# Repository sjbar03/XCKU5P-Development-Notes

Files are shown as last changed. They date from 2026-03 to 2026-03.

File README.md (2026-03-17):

# XCKU5P Development Notes

A repository of all my notes as I learn PCB Design, Xilinx UltraScale+ FPGA, and Vivado.

Huge thanks to the creator of [this repository](https://github.com/tommythorn/AliExpressXCKU5P) for compiling all of the relevant technical info on this board!

Table of Contents
>    [1. VGA](./vga.md)
> 
>    [2. HDMI](./hdmi.md)
> 
>    [3. Protocols](./protocols.md)
> 
>    [4. PCB](./pcb.md)

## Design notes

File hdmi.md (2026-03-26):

# HDMI

19 pin connector, 8 of which are 4 TMDS pairs (1). 

## TMDS 
Encodes 8 bits to 10 bits. First bit is untransformed. Two stages.
1. Next 7 bits is XOR or XNOR transformed against the bit before it. Chooses XOR/XNOR to minimize transitions. Ninth bit represents whether XOR or XNOR was used. 
2. First 8 bits optionally inverted to even out 0s and 1s - sustained DC level. Tenth bit indicates if this happended. (2)

A pair of TMDS signals are complementary: two wires of the pair have opposite signals.

## Transmitter Chip (ADV7513)
Because this FPGA does not have the GTY pins routed, we have to use the HP pins to drive an external transmitter chip. I've chosen to go with the ubiquitous [ADV7513](/Datasheets/C408901%20-%20HDMI.pdf) from Analog Devices. It's very cheap, relatively simple, widely supported, and can handle the HDMI spec I'm going for (1.4). 

We will use HP IO at 1.8V (LVCMOS18) to drive the digital inputs of this chip. We also need to connect a 3.3V power supply, and a 1.8V power supply. 

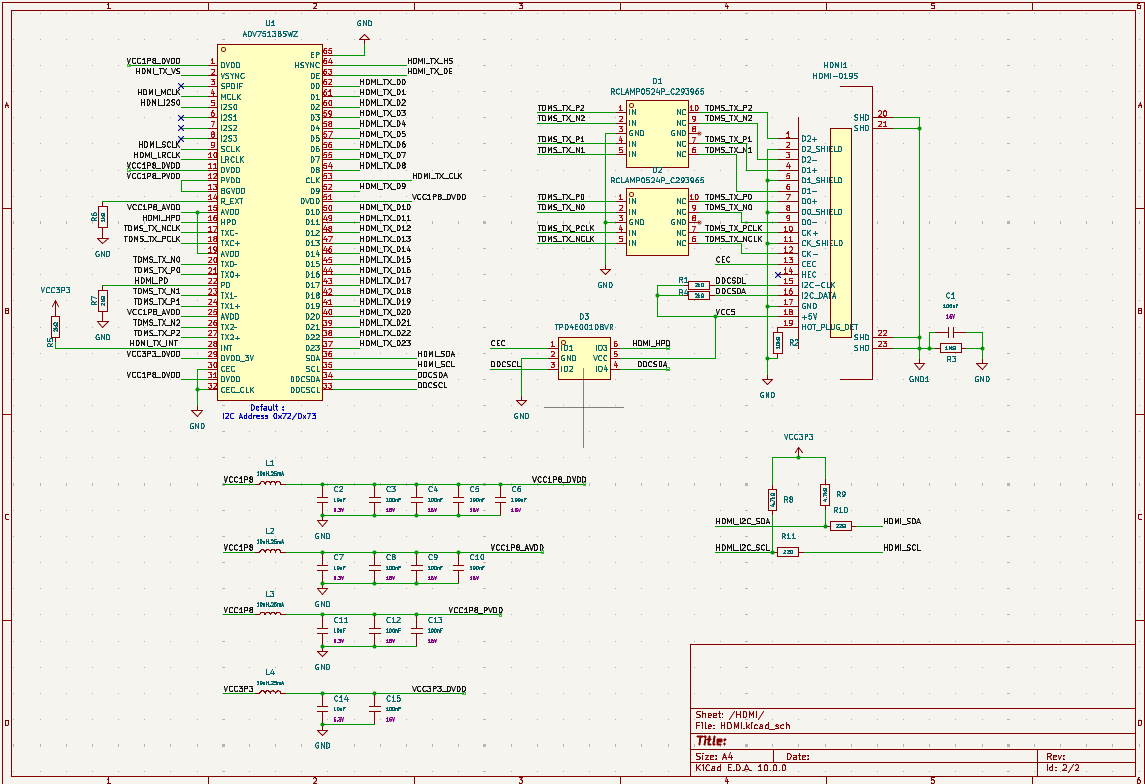
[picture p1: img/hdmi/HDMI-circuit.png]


Above is the circuit I will be using to drive the ADV7513. This circuit is nearly identical to the HDMI circuit used on the [Altera DE10 FPGA](/Datasheets/de10-nano-schematic-711128.pdf).

<!-- ### On FPGA
The XCKU5P does not have HR I/O that support TMDS. The HDMI IP from Xilinx supports GTYE4 for UltraScale+ devices: the GTY pins on this board. I will use the <a href="/Documentation/pg230-vid-phy-controller-en-us-2.2.pdf">Video PHY Controller</a> and <a href="/Documentation/pg235-v-hdmi-tx-ss-en-us-3.2 (1).pdf">HDMI 1.4 TX</a> Xilinx IP. The outputs of the Video PHY Controller can then be exported to the specific GTY pins chosen for the HDMI port.

The HDMI subsystem will be implemented following the HDMI example for the KC705 Evaluation Board. A screenshot of the block diagram can be found <a href="/Documentation/hdmi-subsys-example.pdf">here</a> but directions for loading this example are in PG235 (3p.87).

Pins to be used (tentative)
* AE8   MGTYTXN1_224                 
* AD6   MGTYTXN2_224                 
* AF6   MGTYTXN0_224                 
* AC4   MGTYTXN3_224                 
* AF7   MGTYTXP0_224                 
* AE9   MGTYTXP1_224                 
* AD7   MGTYTXP2_224                 
* AC5   MGTYTXP3_224                 

All of these pins are GTY pins on bank 224. They make up 4 sets of TX differential pairs.

Currently trying to figure out if my core board even exposes the GTY pins. (Not looking good)

## Roadblock
The AliExpress XCKU5P board does not expose any of the GTY pins on the FPGA - so the Xilinx HDMI Transmitter IP cannot be (easily) used for my purposes. Because of this I am switching to implementing VGA using the high-density (at 3.3V) I/O. These notes will remain for future reference.  -->

# Sources
(1) https://www.fpga4fun.com/HDMI.html <cr>
(2) https://en.wikipedia.org/wiki/Transition-minimized_differential_signaling <cr>
(3) https://www.amd.com/content/dam/xilinx/support/documents/ip_documentation/v_hdmi_tx_ss/v3_0/pg235-v-hdmi-tx-ss.pdf <cr>

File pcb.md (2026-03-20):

# PCB Design!

This breakout board is my first PCB design, so I want to take some notes on the progress I'm making.

## VGA Circuit 
I started with the VGA circuit because I have experience with VGA circuits with the RP2040 MCU and it seemed simple. Additionally, video out is an obvious need for FPGA - graphical acceleration is one of the coolest FPGA niches. (Opinion)

### Rev. 1
<div style="text-align:center">
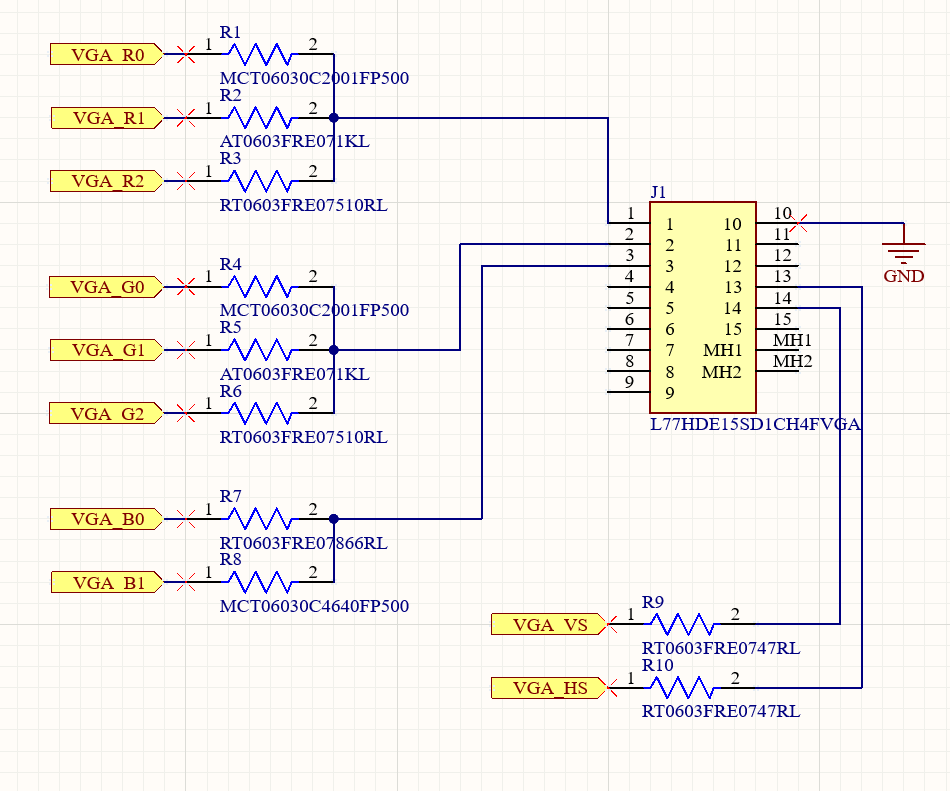
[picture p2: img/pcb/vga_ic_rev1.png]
    
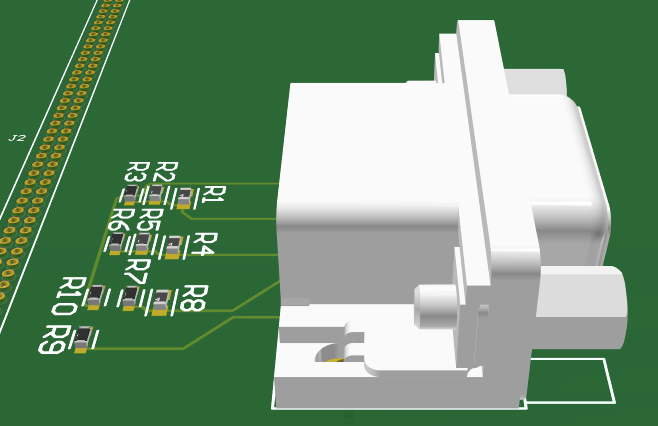
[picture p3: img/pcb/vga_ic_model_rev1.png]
    
</div>

Revision 1! I have the schematic designed and used the Altium auto-router to see what it would look like on the PCB. It's definitely not the final form of this circuit, but it's my first and I think it looks alright.

### Rev. 2
For this revision, I've switched from through hole headers for the receptacles to a surface mount header that allows me to route underneath the header. This is convenient for routing the inner-IO to the edge of the board. Because of this, I was able to re-route the VGA wiring again, and add a 40 pin 0.1" GPIO bank for easy breadboarding. 

I've also added a large GND pour on the 4th layer to connect all GND togethers simply.

<div style="text-align:center">
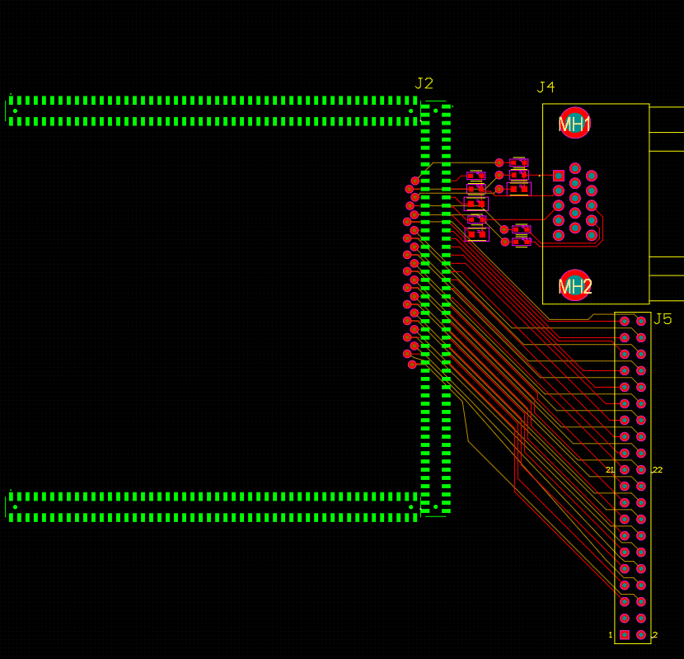
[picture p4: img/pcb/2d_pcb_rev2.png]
    
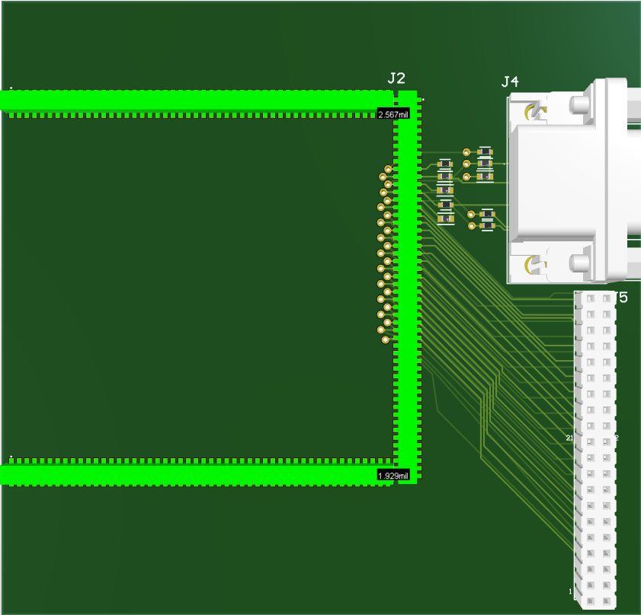
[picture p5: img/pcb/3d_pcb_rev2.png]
    
</div>

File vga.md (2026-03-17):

# VGA 

The VGA protocol is refreshingly simple, and will only use 10 GPIO on the FPGA.

* 3 bits red channel - 3b Ladder DAC
* 3 bits green channel - 3b Ladder DAC
* 2 bits blue channel - 2b Ladder DAC
* 1 bit HSYNC - digital
* 1 bit VSYNC - digital

<div style="text-align:center">
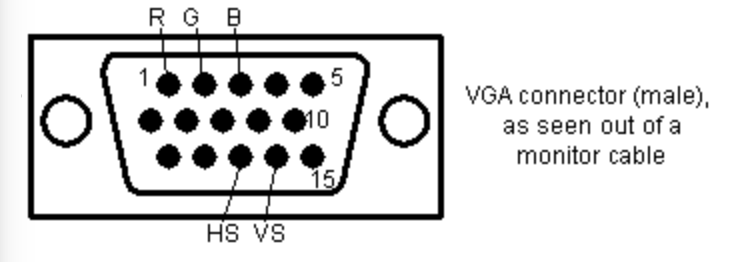
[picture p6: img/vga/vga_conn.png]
    
</div>

Here is a diagram of the VGA Connector with the 5 pins we care about indicated. Taken from (1). 

## Frequency of HD I/O
The high-density I/O on the XCKU5P can operate at 3.3V with a maximum data rate of 250Mb/s DDR (double data rate). For our use case, we will configure these pins to be SDR with a maximum effective rate of 125MHz (plenty fast for the VGA pixel rate).

## Binary Weighted DAC
For simplicity we are going with a Binary Weighted Resistor DAC. This design uses one resistor per bit, so we'll need 8 total (3 for Red, 3 for Green, 2 for Blue). I've drafted the circuit in LTspice and included an image below. In this circuit, I inclued the 75Ohm terminating resistor that is found inside most VGA monitors. I have also included a waveform of the spice simulation showing the output voltage at each step.

<div style="text-align:center">
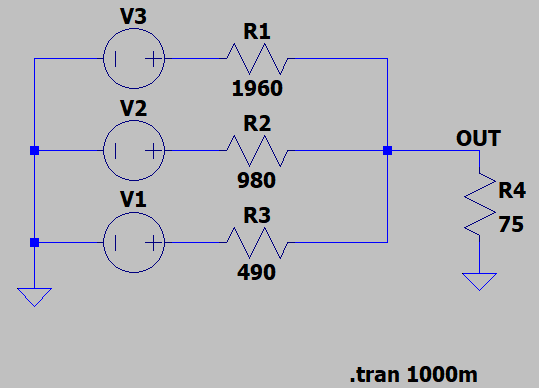
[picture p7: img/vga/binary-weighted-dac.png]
    
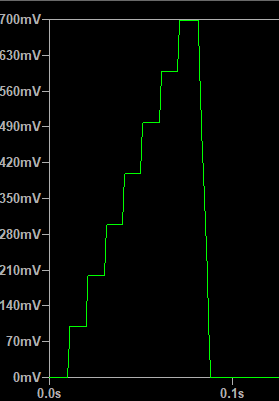
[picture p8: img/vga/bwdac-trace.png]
    
</div>

### BWD Math
The math for the binary weighted DAC is simple. We want our output signal to be 0V to 0.7V, and our input volatge is 3.3V. For a simple voltage divider, we would need a resistance of 325 Ohms to achieve an output of 0.7V.

$$ V_{out} = V_{in} * \frac{R_2}{R_1 + R_2} $$

$$ R_1 = (R_2 * \frac{V_{in}}{V_{out}}) - R2 $$

$$ R_1 = (75\Omega * \frac{3.3V}{0.7V}) - 75\Omega \approx 280 \Omega $$

We just calculated the Thevenin Resistance of the DAC looking from the output. We want to turn this into a set of three resistances weighted appropriately to represent the magnitude of each bit. Lower order bits should get higher resistance (larger division) and vice-versa.

$$ \frac{1}{R_0} + \frac{1}{2R_0} + \frac{1}{4R_0} = \frac{1}{R_1} $$
$$ R_0 = 490 $$
$$ R_{B0} = 1960, R_{B1} = 980, R_{B2} = 490 $$

These are the theoretical resistor values for each bit in a three bit DAC. In reality, we will choose the closest available resistor - above the desired value (to prevent over-voltage). We also calculate for a two bit DAC.

$$ \frac{1}{R_0} + \frac{1}{2R_0} = \frac{1}{R_1} $$
$$ R_0 = 420 $$
$$ R_{B0} = 840, R_{B1} = 420 $$

Now we have our full Digital to Analog VGA circuit - ready to be drafted and put on a PCB.

## FPGA Implementation

For this use case, we're going to need 8 pins for color, 1 pin for HSync, and 1 pin for VSync. 10 pins total! This is super light for video output, which is why I chose VGA for my first breakout board design.

Since we're using the HD pins on the AliExpress board we'll choose 10 adjacent pins from our pinout: 

    * AD15 - RED[2]
    * AF15 - GREEN[2]
    * AF14 - RED[1]
    * AF13 - GREEN[1]
    * AE15 - RED[0]
    * AE13 - GREEN[0]
    * AD14 - HS
    * AD13 - BLUE[0]
    * AC14 - VS
    * AC13 - BLUE[1]

These pins are all in the J2 bank on the AliExpress board, specifically bank 84. I chose adjacent pins in the same bank for consistency, and I assigned pins to each signal in an attempt to prioritize shorter runs for more important signals.

Here are two images of the current design.

<div style="text-align:center">
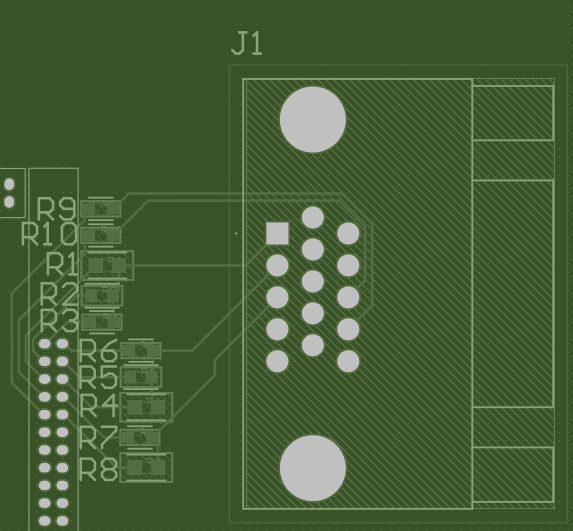
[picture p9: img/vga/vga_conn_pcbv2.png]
    
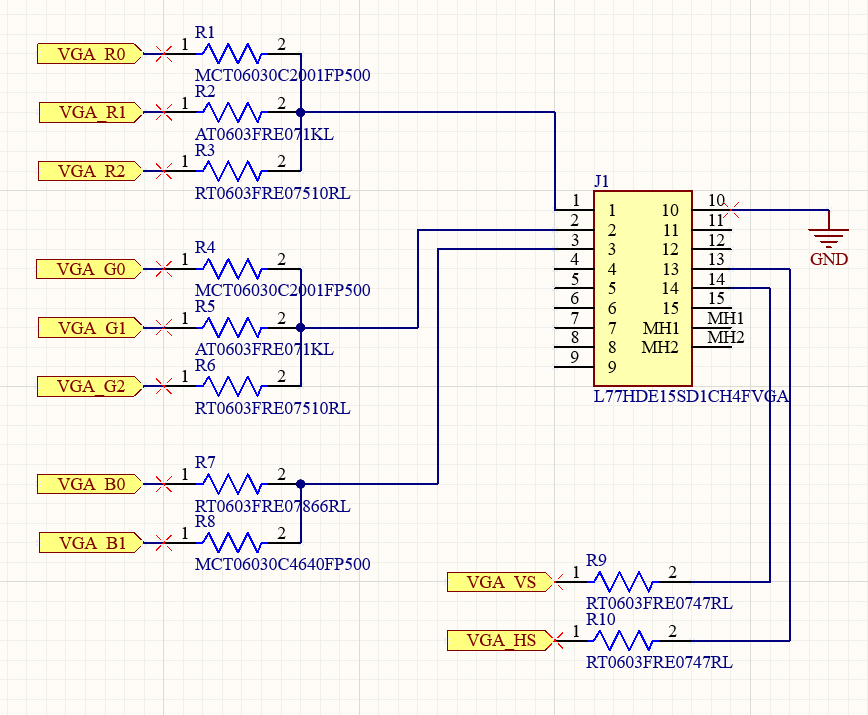
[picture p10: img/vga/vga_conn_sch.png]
    
</div>

I will have to implement the VGA driver from scratch since there is no Xilinx IP, although I will have plenty of inspiration to go off of. Two great reference for a Verilog VGA driver is FPGA4FUN (1) and Hunter Adam's + Bruce Land's ECE5760 (4).

# Sources
(1) https://www.fpga4fun.com/VGA.html <cr>

(2) https://austinmorlan.com/posts/fpga_computer_vga/

(3) https://www.electronics-tutorials.ws/combination/digital-to-analogue-converter.html

(4) https://people.ece.cornell.edu/land/courses/ece5760/DE1_SOC/HPS_peripherials/Examples_version_18.html

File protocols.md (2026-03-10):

## LVDS
These TMDS pairs would typically be implemented on HR pins (older Xilinx). The XCKU5P only has HD and HP IO banks - we'll use high-performance and go with a 1.8V LVDS (Low Voltage Differential Signaling) (1p.121)

Only available on the HP I/O Banks
* $V_{CCO}$ = 1.8v
* DIFF_TERM_ADV = TERM_100
* DIFF_TERM = TRUE

<div style="text-align:center">
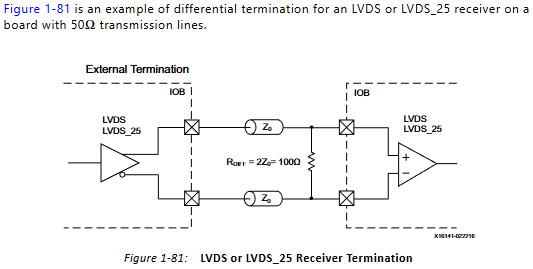
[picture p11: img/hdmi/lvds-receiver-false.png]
    
</div>

An example of the receiver circuitry if DIFF_TERM = FALSE.

<div style="text-align:center">
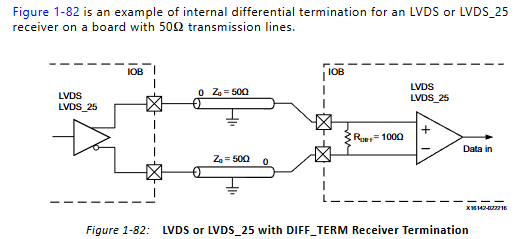
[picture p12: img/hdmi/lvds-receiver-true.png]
    
</div>

And an example of the receiver circuitry if DIFF_TERM = TRUE. This is what I will be going with in this project. Note the formula:

$$R_{DIFF} = 2Z_0$$

This indicates that DIFF_TERM_ADV should be adjusted according to the resistance in the transmission lines.

# Sources
(1) https://docs.amd.com/v/u/en-US/ug571-ultrascale-selectio

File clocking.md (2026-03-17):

# Clocking and MMCM
This AliExpress XCKU5P comes with one 100MHz crystal oscillator onboard. This oscillator is terminated to FPGA pins T25 and U25 as an LVDS differential pair (P and N, respectively).

Deriving a single-ended clock signal from this pair can be done like so: 

    IBUFDS clk_buf (
        .I(clk_p),
        .IB(clk_n),
        .O(clk)
    );

## MMCM Multiplication
If 100MHz is too slow (as it hopefully will be!), we can multiply this clock using the Mixed Mode Clock Manager primitives provided in Vivado. Docs on the MMCM are <a href=https://docs.amd.com/r/en-US/ug572-ultrascale-clocking/MMCM-Ports>here</a>

In general, MMCM can be used like this: (taken from Google AI Result, will be refined later)

    MMCME4_BASE #(
    .BANDWIDTH("OPTIMIZED"),   // Jitter programming
    .CLKFBOUT_MULT_F(12.0),    // Multiply value (2.000-64.000)
    .CLKFBOUT_PHASE(0.0),      // Phase offset of feedback
    .CLKIN1_PERIOD(10.0),      // Input period in ns (100 MHz)
    .CLKOUT0_DIVIDE_F(6.0),    // Divide value for CLKOUT0 (resulting in 200MHz)
    .CLKOUT0_DUTY_CYCLE(0.5),
    .CLKOUT0_PHASE(0.0),
    .DIVCLK_DIVIDE(1)          // Master division value (1-106)
    )
    MMCME4_BASE_inst (
    .CLKOUT0(clk_200mhz),      // 200 MHz output clock
    .CLKFBOUT(clk_fb),         // Feedback clock output
    .CLKFBIN(clk_fb),          // Feedback clock input
    .CLKIN1(clk_100mhz),       // 100 MHz input clock
    .PWRDWN(1'b0),             // Power down signal
    .RST(reset),               // Reset signal
    .LOCKED(locked)            // Output indicating clock is stable
    );

We want our VCO to operate in its safe range, which is 800MHz to 1600MHz on the Kintex UltraScale+ FPGAs. Multiplying by 12 will allow our VCO to run at 1200MHz, then divided by 6 to achieve 200MHz output on clk200mhz.

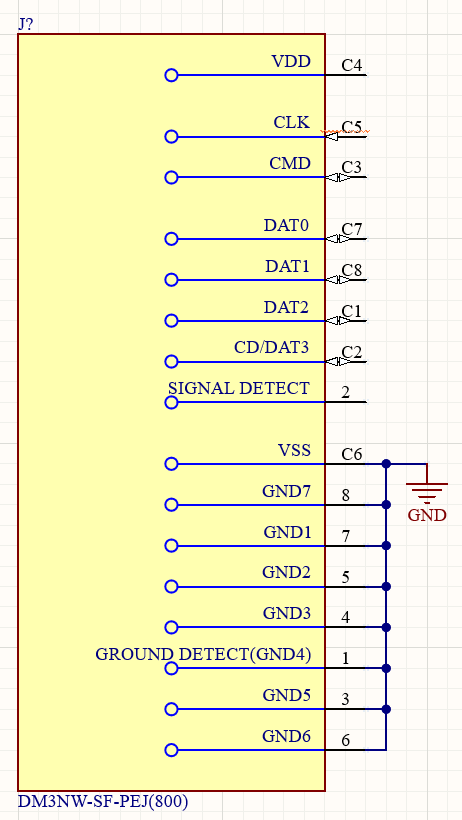
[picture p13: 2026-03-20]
img/sdcard/pinout.png

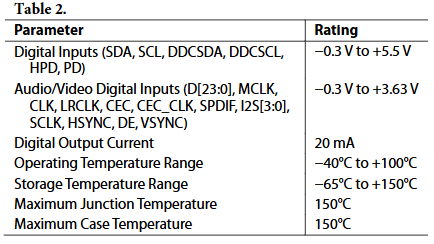
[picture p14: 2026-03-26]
img/hdmi/ADV-inputs.png

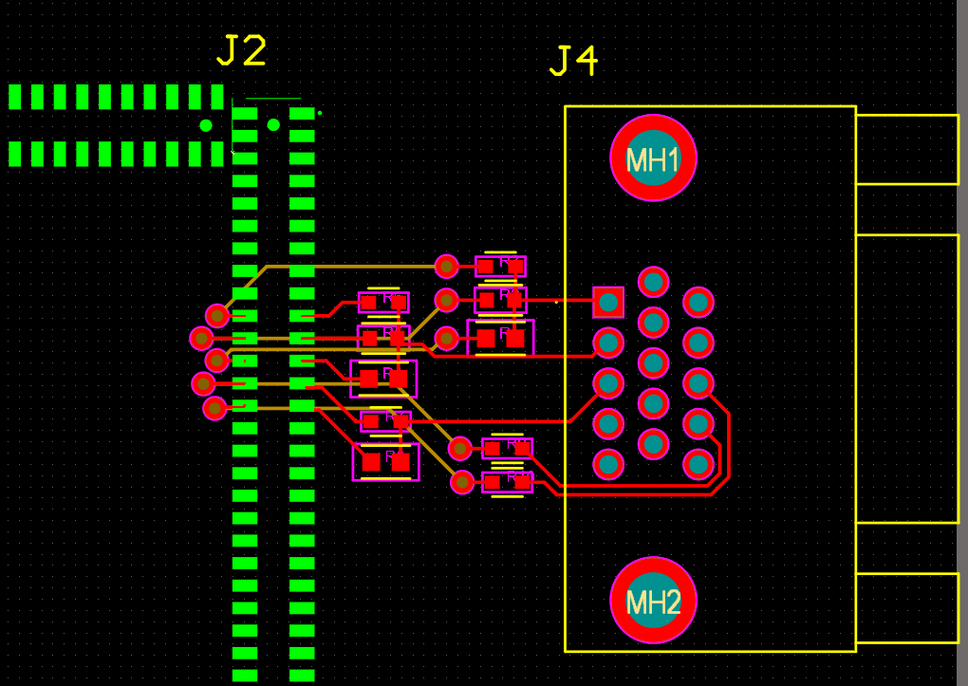
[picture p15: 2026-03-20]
img/pcb/vga_ic_rev2.png

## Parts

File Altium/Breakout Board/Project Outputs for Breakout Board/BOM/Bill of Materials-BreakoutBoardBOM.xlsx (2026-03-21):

Line # | Name | Description | Designator | Revision ID | Revision State | Revision Status | Quantity | LCSC Part Number | Manufacturer 1 | Manufacturer Part Number 1 | Manufacturer Lifecycle 1 | Supplier 1 | Supplier Part Number 1 | Supplier Unit Price 1 | Supplier Subtotal 1 | Footprint
 | DM3AT-SF-PEJM5 | Connector | J6 |  | Not managed |  | 1 | C114218 | HIROSE ELECTRIC | DM3AT-SF-PEJM5 | Volume Production | Mouser | 798-DM3AT-SF-PEJM5 | 2.66 | 2.66 | DM3ATSFPEJM5
 | LTST-C190KRKT | LED | LED0, LED1, LED2, LED3, LED4, LED5, LED6, LED7 |  | Not managed |  | 8 | C94869 | Lite-On | LTST-C190KRKT | Volume Production | Conrad | 1127460 | 0.05786 | 0.46286 | LEDC1608X80N
 | 0402WGF2001TCE | Resistor, 2kΩ, ±1%, 62.5mW, 50V, ±100ppm/℃, -55℃~+155℃, SMD 0402 | R1, R4 |  | Not managed |  | 2 | C4109 |  |  |  | LCSC | C4109 |  |  | RES-0402
 | 0402WGF1001TCE | Resistor, 1kΩ, ±1%, 62.5mW, 50V, ±100ppm/℃, -55℃~+155℃, SMD 0402 | R2, R5 |  | Not managed |  | 2 | C11702 |  |  |  | LCSC | C11702 |  |  | RES-0402
 | 0402WGF5100TCE | Resistor, 510Ω, ±1%, 62.5mW, 50V, ±100ppm/℃, -55℃~+155℃, SMD 0402 | R3, R6, R8 |  | Not managed |  | 3 | C25123 |  |  |  | LCSC | C25123 |  |  | RES-0402
 | 0603WAF8200T5E | Resistor, 820Ω, ±1%, 100mW, 75V, ±100ppm/℃, -55℃~+155℃, SMD 0603 | R7 |  | Not managed |  | 1 | C23253 |  |  |  | LCSC | C23253 |  |  | RES-0603
 | 0603WAF470JT5E | Resistor, 47Ω, ±1%, 100mW, 75V, ±100ppm/℃, -55℃~+155℃, SMD 0603 | R9, R10 |  | Not managed |  | 2 | C23182 |  |  |  | LCSC | C23182 |  |  | RES-0603
 | 0603WAF1002T5E | Resistor, 10kΩ, ±1%, 100mW, 75V, ±100ppm/℃, -55℃~+155℃, SMD 0603 | R11, R12, R13, R14, R15, R16, R17, R18, R19, R20, R21, R22, R23, R24 |  | Not managed |  | 14 | C25804 |  |  |  | LCSC | C25804 |  |  | RES-0603
 | 0402WGF2000TCE | Resistor, 200Ω, ±1%, 62.5mW, 50V, ±100ppm/℃, -55℃~+155℃, SMD 0402 | R25, R26, R27, R28, R29, R30, R31, R32 |  | Not managed |  | 8 | C25087 |  |  |  | LCSC | C25087 |  |  | RES-0402
 | JS202011JCQN | SWITCH SLIDE DPDT 300MA 6V | SW0, SW1, SW2, SW3, SW4, SW5, SW6, SW7, SW8, SW9 | CMP-10038-000009-1 | New From Design | Up to date | 10 | C221665 | C&K Components | JS202011JCQN | Volume Production | DigiKey | CKN10723CT-ND | 0.738 | 7.38 | FP-JS202011JCQN-MFG
 | TS-1185-B-A-B-A | Tactile switch ROHS, SPST Surface Mount, -30C +85C 1.6N 12V 2mm 3mm 4mm 50mA Black no round button | SW10, SW11, SW12, SW13 |  | Not managed |  | 4 | C561517 |  |  |  |  |  |  |  | TS-1185-B-A-B-A

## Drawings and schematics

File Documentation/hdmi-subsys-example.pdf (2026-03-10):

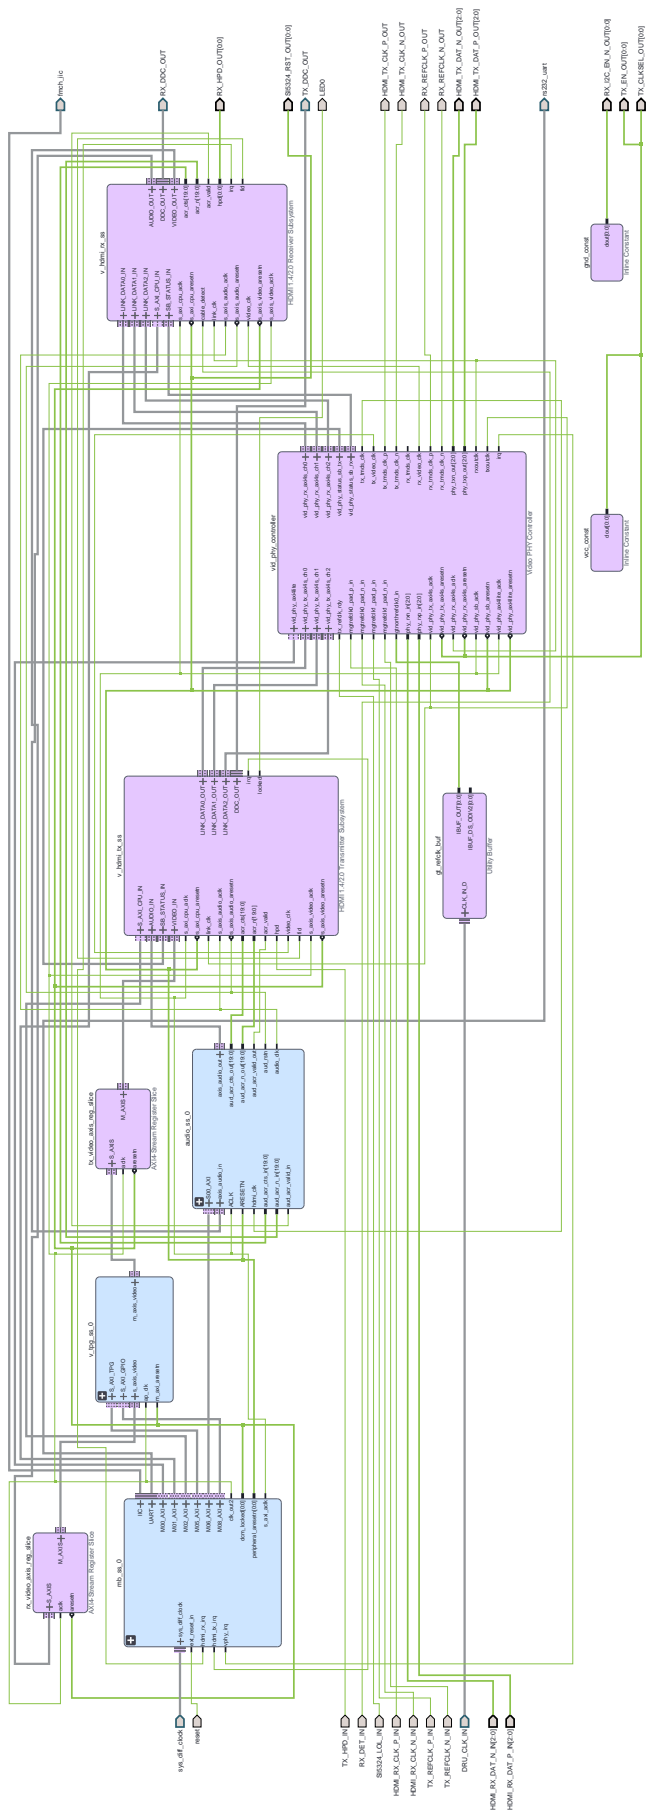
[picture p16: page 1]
DRU_CLK_IN; HDMI_RX_DAT_N_IN[2:0]; HDMI_RX_DAT_P_IN[2:0]; RX_DDC_OUT; RX_HPD_OUT[0:0]; SI5324_RST_OUT[0:0]; TX_DDC_OUT; HDMI_TX_DAT_N_OUT[2:0]; HDMI_TX_DAT_P_OUT[2:0]; RX_I2C_EN_N_OUT[0:0]; TX_EN_OUT[0:0]; TX_CLKSEL_OUT[0:0]; audio_ss_0; S00_AXI; axis_audio_in axis_audio_out ACLK; ARESETN; hdmi_clk; aud_acr_cts_in[19:0]; aud_acr_n_in[19:0]; aud_acr_valid_in; aud_acr_cts_out[19:0]; aud_acr_n_out[19:0]; aud_acr_valid_out; aud_rstn; audio_clk; fmch_iic; gnd_const; Inline Constant; dout[0:0]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

HDMI 1.4/2.0 Receiver Subsystem

Video PHY Controller

HDMI 1.4/2.0 Transmitter Subsystem

AXI4-Stream Register Slice

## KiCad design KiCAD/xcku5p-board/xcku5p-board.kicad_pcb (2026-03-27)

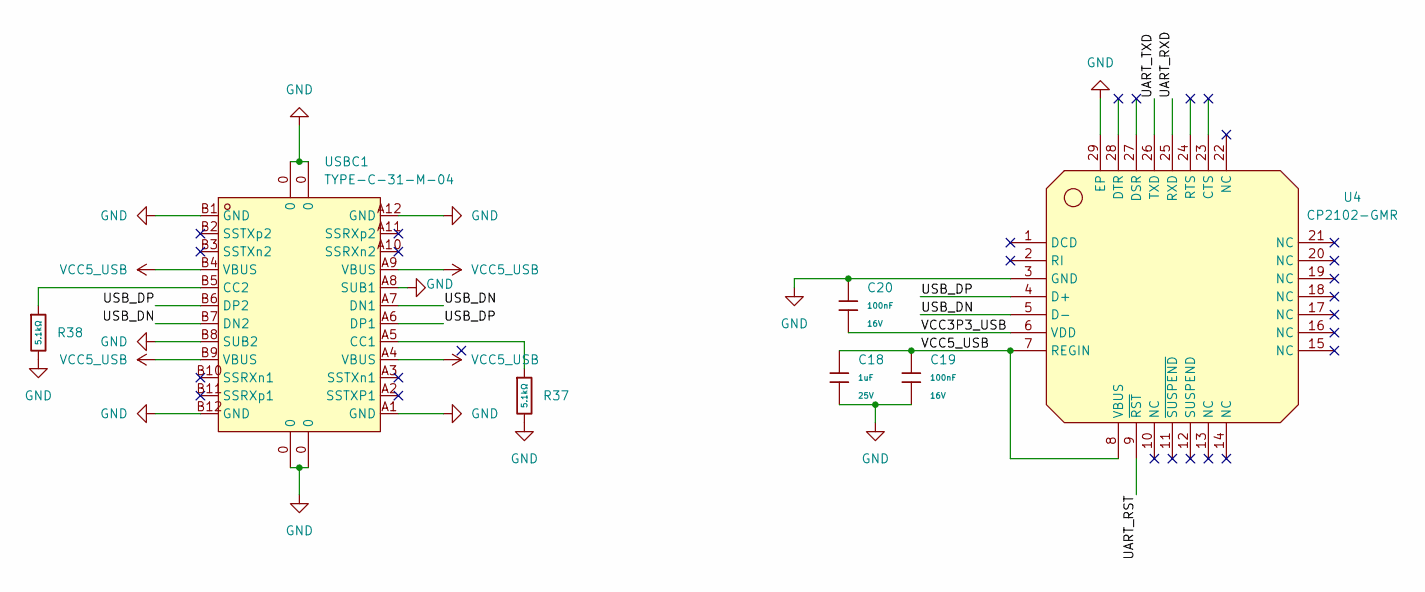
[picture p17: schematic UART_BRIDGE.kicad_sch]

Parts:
C18: 1uF; C_0402; Voltage Rated 25V; Tolerance ±10%; Part CL05A105KA5NQNC; LCSC C52923
C19, C20: 100nF; C_0402; Voltage Rated 16V; Tolerance ±10%; Part CL05B104KO5NNNC; LCSC C1525
R37, R38: 5.1kΩ; R_0402; Overload Voltage (Max) 50V; Tolerance ±1%; Part 0402WGF5101TCE; LCSC C25905
U4: CP2102-GMR; WQFN-28_L5.0-W5.0-P0.50-BL-EP3.2; LCSC Part C6568
USBC1: TYPE-C-31-M-04; USB-C-SMD_TYPE-C-USB-20; LCSC Part C129018

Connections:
/UART_BRIDGE/UART_RST: U4.9 (~RST)
/UART_BRIDGE/UART_RXD: U4.25 (RXD)
/UART_BRIDGE/UART_TXD: U4.26 (TXD)
/UART_BRIDGE/USB_DN: U4.5 (D-), USBC1.A7 (DN1), USBC1.B7 (DN2)
/UART_BRIDGE/USB_DP: U4.4 (D+), USBC1.A6 (DP1), USBC1.B6 (DP2)
/UART_BRIDGE/VCC3P3_USB: C20.2, U4.6 (VDD)
GND: C18.2, C19.2, C20.1, R37.2, R38.2, U4.3 (GND), U4.29 (EP), USBC1.0, USBC1.A1 (GND), USBC1.A8 (SUB1), USBC1.A12 (GND), USBC1.B1 (GND), USBC1.B8 (SUB2), USBC1.B12 (GND); also elsewhere on the board
unnamed: R37.1, USBC1.A5 (CC1)
unnamed: R38.1, USBC1.B5 (CC2)
VCC5_USB: C18.1, C19.1, U4.7 (REGIN), U4.8 (VBUS), USBC1.A4 (VBUS), USBC1.A9 (VBUS), USBC1.B4 (VBUS), USBC1.B9 (VBUS)

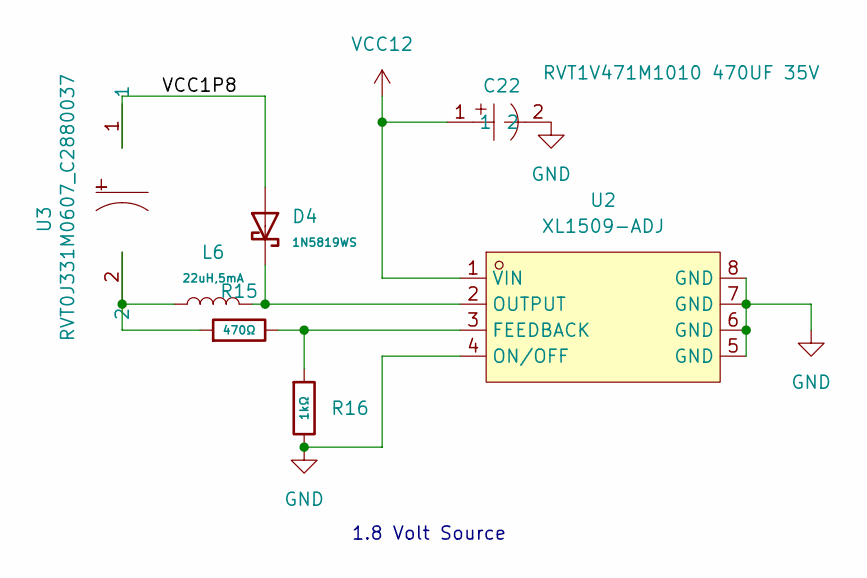
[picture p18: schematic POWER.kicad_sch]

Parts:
C22: RVT1V471M1010 470UF 35V; CAP-SMD_BD10.0-L10.3-W10.3-FD; LCSC Part C976030
D4: 1N5819WS; D_SOD-323; Forward Voltage (Vf@If) 600mV@1A; Reverse Voltage (Vr) 40V; Part 1N5819WS; LCSC C191023
L6: 22uH,5mA; L_0805; Tolerance ±10%; Part SDFL2012T220KTF; LCSC C32375
R15: 470Ω; R_0402; Overload Voltage (Max) 50V; Tolerance ±1%; Part 0402WGF4700TCE; LCSC C25117
R16: 1kΩ; R_0402; Overload Voltage (Max) 50V; Tolerance ±1%; Part 0402WGF1001TCE; LCSC C11702
U2: XL1509-ADJ; SOIC-8_L5.0-W4.0-P1.27-LS6.0-BL; LCSC Part C2681227
U3: RVT0J331M0607_C2880037; CAP-SMD_BD6.3-L6.6-W6.6-LS7.2-R-RD-1; LCSC Part C2880037

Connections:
/POWER/VCC1P8: D4.2, U3.1
GND: C22.2, R16.2, U2.4 (ON/OFF), U2.5 (GND), U2.6 (GND), U2.7 (GND), U2.8 (GND); also elsewhere on the board
unnamed: L6.1, R15.1, U3.2
unnamed: R15.2, R16.1, U2.3 (FEEDBACK)
unnamed: D4.1, L6.2, U2.2 (OUTPUT)
VCC12: C22.1, U2.1 (VIN)

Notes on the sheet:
1.8 Volt Source

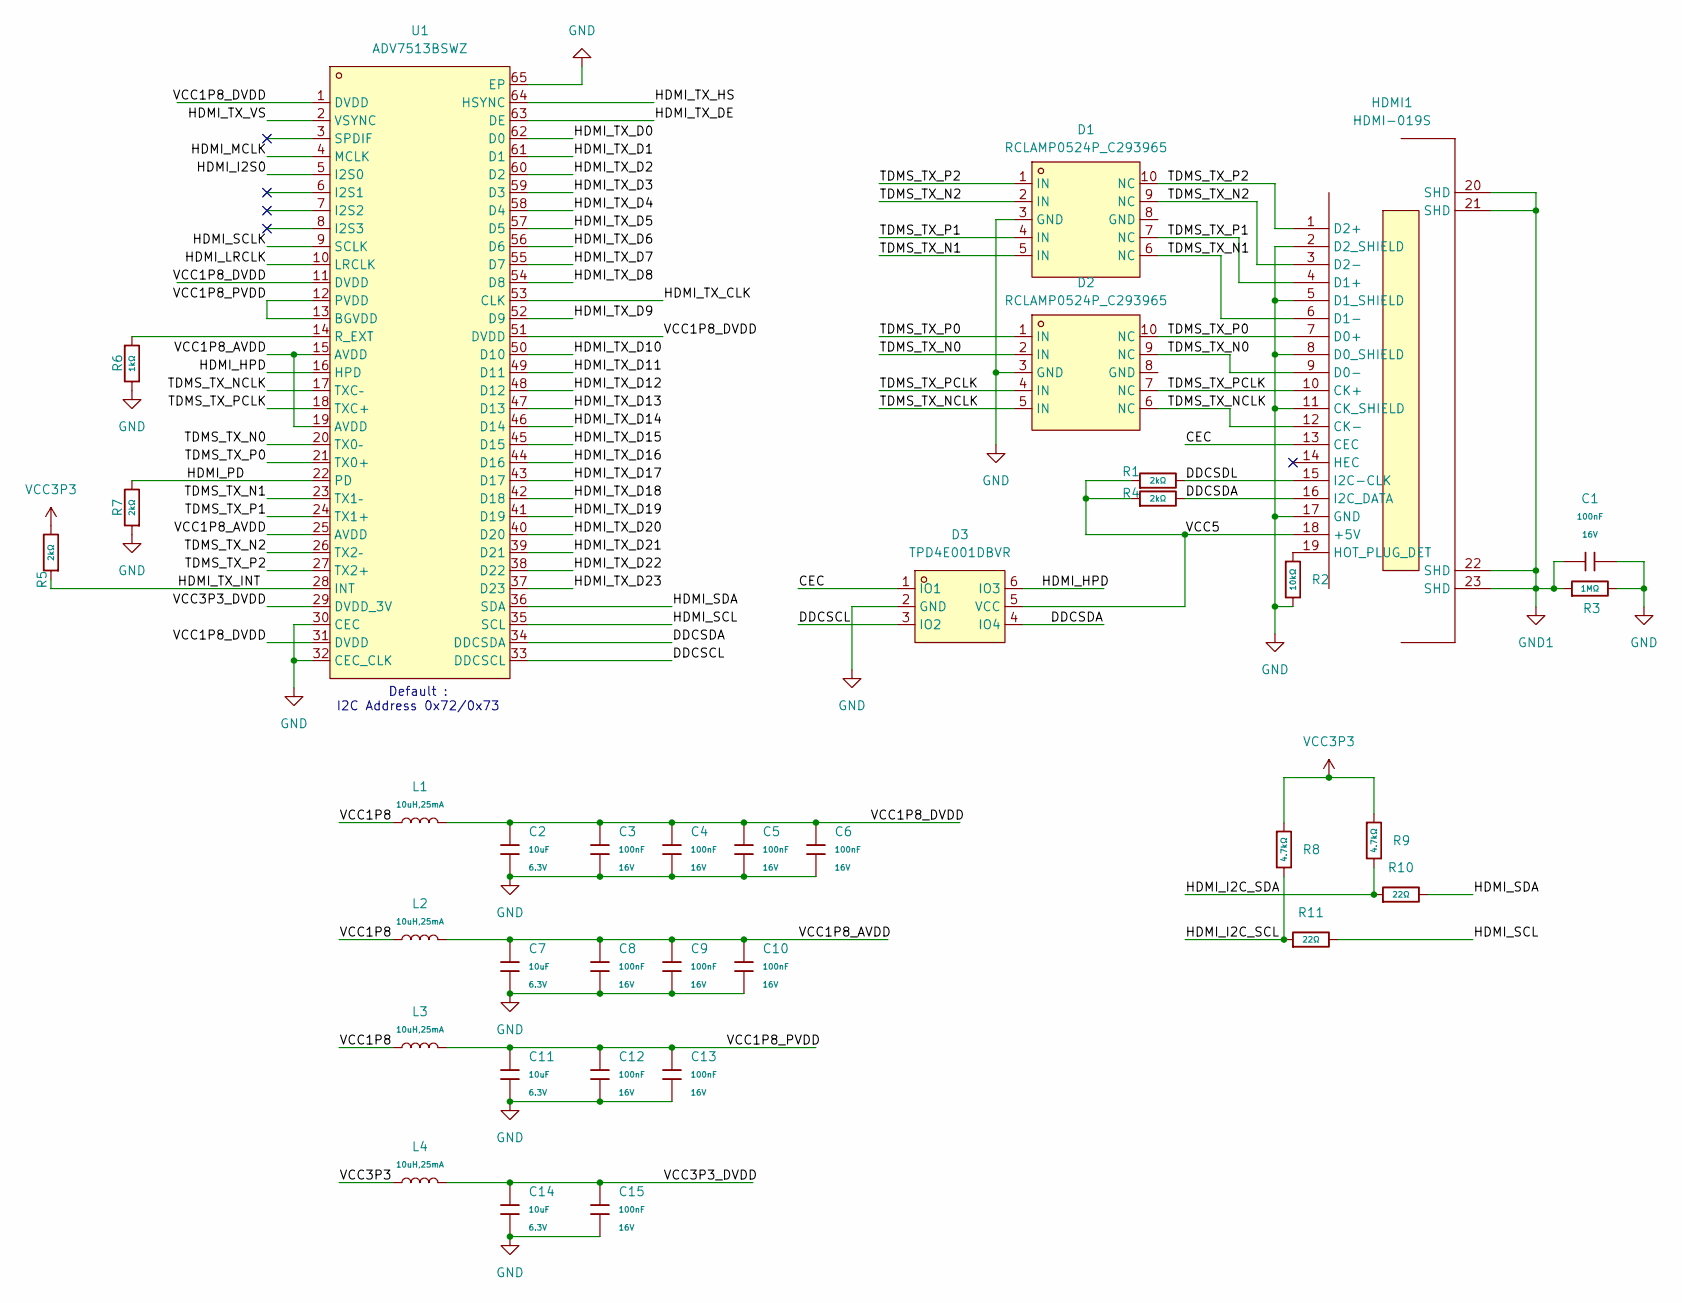
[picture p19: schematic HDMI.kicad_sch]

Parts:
C1, C3, C4, C5, C6, C8, C9, C10, C12, C13, C15: 100nF; C_0402; Voltage Rated 16V; Tolerance ±10%; Part CL05B104KO5NNNC; LCSC C1525
C2, C7, C11, C14: 10uF; C_0402; Voltage Rated 6.3V; Tolerance ±20%; Part CL05A106MQ5NUNC; LCSC C15525
D1, D2: RCLAMP0524P_C293965; DFN2510-10_L2.5-W1.0-P0.50-BL; LCSC Part C293965
D3: TPD4E001DBVR; SOT-23-6_L2.9-W1.6-P0.95-LS2.8-BL; LCSC Part C465736
HDMI1: HDMI-019S; HDMI-SMD_HDMI-019S; LCSC Part C111617
L1, L2, L3, L4: 10uH,25mA; L_1206; Tolerance ±10%; Part CMI321609X100KT; LCSC C1051
R1, R4, R5, R7: 2kΩ; R_0402; Overload Voltage (Max) 50V; Tolerance ±1%; Part 0402WGF2001TCE; LCSC C4109
R2: 10kΩ; R_0402; Overload Voltage (Max) 50V; Tolerance ±1%; Part 0402WGF1002TCE; LCSC C25744
R3: 1MΩ; R_0402; Overload Voltage (Max) 50V; Tolerance ±1%; Part 0402WGF1004TCE; LCSC C26083
R6: 1kΩ; R_0402; Overload Voltage (Max) 50V; Tolerance ±1%; Part 0402WGF1001TCE; LCSC C11702
R8, R9: 4.7kΩ; R_0402; Overload Voltage (Max) 50V; Tolerance ±1%; Part 0402WGF4701TCE; LCSC C25900
R10, R11: 22Ω; R_0402; Overload Voltage (Max) 50V; Tolerance ±1%; Part 0402WGF220JTCE; LCSC C25092
U1: ADV7513BSWZ; LQFP-64_L10.0-W10.0-P0.50-LS12.0-BL-EP5.3; LCSC Part C408901

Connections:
/HDMI/CEC: D3.1 (IO1), HDMI1.13 (CEC)
/HDMI/DDCSCL: D3.3 (IO2), U1.33 (DDCSCL)
/HDMI/DDCSDA: D3.4 (IO4), HDMI1.16 (I2C_DATA), R4.2, U1.34 (DDCSDA)
/HDMI/DDCSDL: HDMI1.15 (I2C-CLK), R1.2
/HDMI/HDMI_HPD: D3.6 (IO3), U1.16 (HPD)
/HDMI/HDMI_I2C_SCL: R8.2, R11.1
/HDMI/HDMI_I2C_SDA: R9.2, R10.1
/HDMI/HDMI_I2S0: U1.5 (I2S0)
/HDMI/HDMI_LRCLK: U1.10 (LRCLK)
/HDMI/HDMI_MCLK: U1.4 (MCLK)
/HDMI/HDMI_PD: R7.2, U1.22 (PD)
/HDMI/HDMI_SCL: R11.2, U1.35 (SCL)
/HDMI/HDMI_SCLK: U1.9 (SCLK)
/HDMI/HDMI_SDA: R10.2, U1.36 (SDA)
/HDMI/HDMI_TX_CLK: U1.53 (CLK)
/HDMI/HDMI_TX_D0: U1.62 (D0)
/HDMI/HDMI_TX_D1: U1.61 (D1)
/HDMI/HDMI_TX_D2: U1.60 (D2)
/HDMI/HDMI_TX_D3: U1.59 (D3)
/HDMI/HDMI_TX_D4: U1.58 (D4)
/HDMI/HDMI_TX_D5: U1.57 (D5)
/HDMI/HDMI_TX_D6: U1.56 (D6)
/HDMI/HDMI_TX_D7: U1.55 (D7)
/HDMI/HDMI_TX_D8: U1.54 (D8)
/HDMI/HDMI_TX_D9: U1.52 (D9)
/HDMI/HDMI_TX_D10: U1.50 (D10)
/HDMI/HDMI_TX_D11: U1.49 (D11)
/HDMI/HDMI_TX_D12: U1.48 (D12)
/HDMI/HDMI_TX_D13: U1.47 (D13)
/HDMI/HDMI_TX_D14: U1.46 (D14)
/HDMI/HDMI_TX_D15: U1.45 (D15)
/HDMI/HDMI_TX_D16: U1.44 (D16)
/HDMI/HDMI_TX_D17: U1.43 (D17)
/HDMI/HDMI_TX_D18: U1.42 (D18)
/HDMI/HDMI_TX_D19: U1.41 (D19)
/HDMI/HDMI_TX_D20: U1.40 (D20)
/HDMI/HDMI_TX_D21: U1.39 (D21)
/HDMI/HDMI_TX_D22: U1.38 (D22)
/HDMI/HDMI_TX_D23: U1.37 (D23)
/HDMI/HDMI_TX_DE: U1.63 (DE)
/HDMI/HDMI_TX_HS: U1.64 (HSYNC)
/HDMI/HDMI_TX_INT: R5.1, U1.28 (INT)
/HDMI/HDMI_TX_VS: U1.2 (VSYNC)
/HDMI/TDMS_TX_N0: D2.2 (IN), D2.9 (NC), HDMI1.9 (D0-), U1.20 (TX0–)
/HDMI/TDMS_TX_N1: D1.5 (IN), D1.6 (NC), HDMI1.6 (D1-), U1.23 (TX1–)
/HDMI/TDMS_TX_N2: D1.2 (IN), D1.9 (NC), HDMI1.3 (D2-), U1.26 (TX2–)
/HDMI/TDMS_TX_NCLK: D2.5 (IN), D2.6 (NC), HDMI1.12 (CK-), U1.17 (TXC–)
/HDMI/TDMS_TX_P0: D2.1 (IN), D2.10 (NC), HDMI1.7 (D0+), U1.21 (TX0+)
/HDMI/TDMS_TX_P1: D1.4 (IN), D1.7 (NC), HDMI1.4 (D1+), U1.24 (TX1+)
/HDMI/TDMS_TX_P2: D1.1 (IN), D1.10 (NC), HDMI1.1 (D2+), U1.27 (TX2+)
/HDMI/TDMS_TX_PCLK: D2.4 (IN), D2.7 (NC), HDMI1.10 (CK+), U1.18 (TXC+)
/HDMI/VCC1P8: L1.1, L2.1, L3.1
/HDMI/VCC1P8_AVDD: C7.1, C8.2, C9.2, C10.2, L2.2, U1.15 (AVDD), U1.19 (AVDD), U1.25 (AVDD)
/HDMI/VCC1P8_DVDD: C2.1, C3.2, C4.2, C5.2, C6.2, L1.2, U1.1 (DVDD), U1.11 (DVDD), U1.31 (DVDD), U1.51 (DVDD)
/HDMI/VCC1P8_PVDD: C11.1, C12.2, C13.2, L3.2, U1.12 (PVDD), U1.13 (BGVDD)
/HDMI/VCC3P3_DVDD: C14.1, C15.2, L4.2, U1.29 (DVDD_3V)
/HDMI/VCC5: D3.5 (VCC), HDMI1.18 (+5V), R1.1, R4.1
GND: C1.2, C2.2, C3.1, C4.1, C5.1, C6.1, C7.2, C8.1, C9.1, C10.1, C11.2, C12.1, C13.1, C14.2, C15.1, D1.3 (GND), D2.3 (GND), D3.2 (GND), HDMI1.2 (D2_SHIELD), HDMI1.5 (D1_SHIELD), HDMI1.8 (D0_SHIELD), HDMI1.11 (CK_SHIELD), HDMI1.17 (GND), R2.2, R3.2, R6.2, R7.1, U1.30 (CEC), U1.32 (CEC_CLK), U1.65 (EP); also elsewhere on the board
GND1: C1.1, HDMI1.20 (SHD), HDMI1.21 (SHD), HDMI1.22 (SHD), HDMI1.23 (SHD), R3.1
unnamed: HDMI1.19 (HOT_PLUG_DET), R2.1
unnamed: R6.1, U1.14 (R_EXT)
VCC3P3: L4.1, R5.2, R8.1, R9.1; also elsewhere on the board

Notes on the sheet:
Default : I2C Address 0x72/0x73

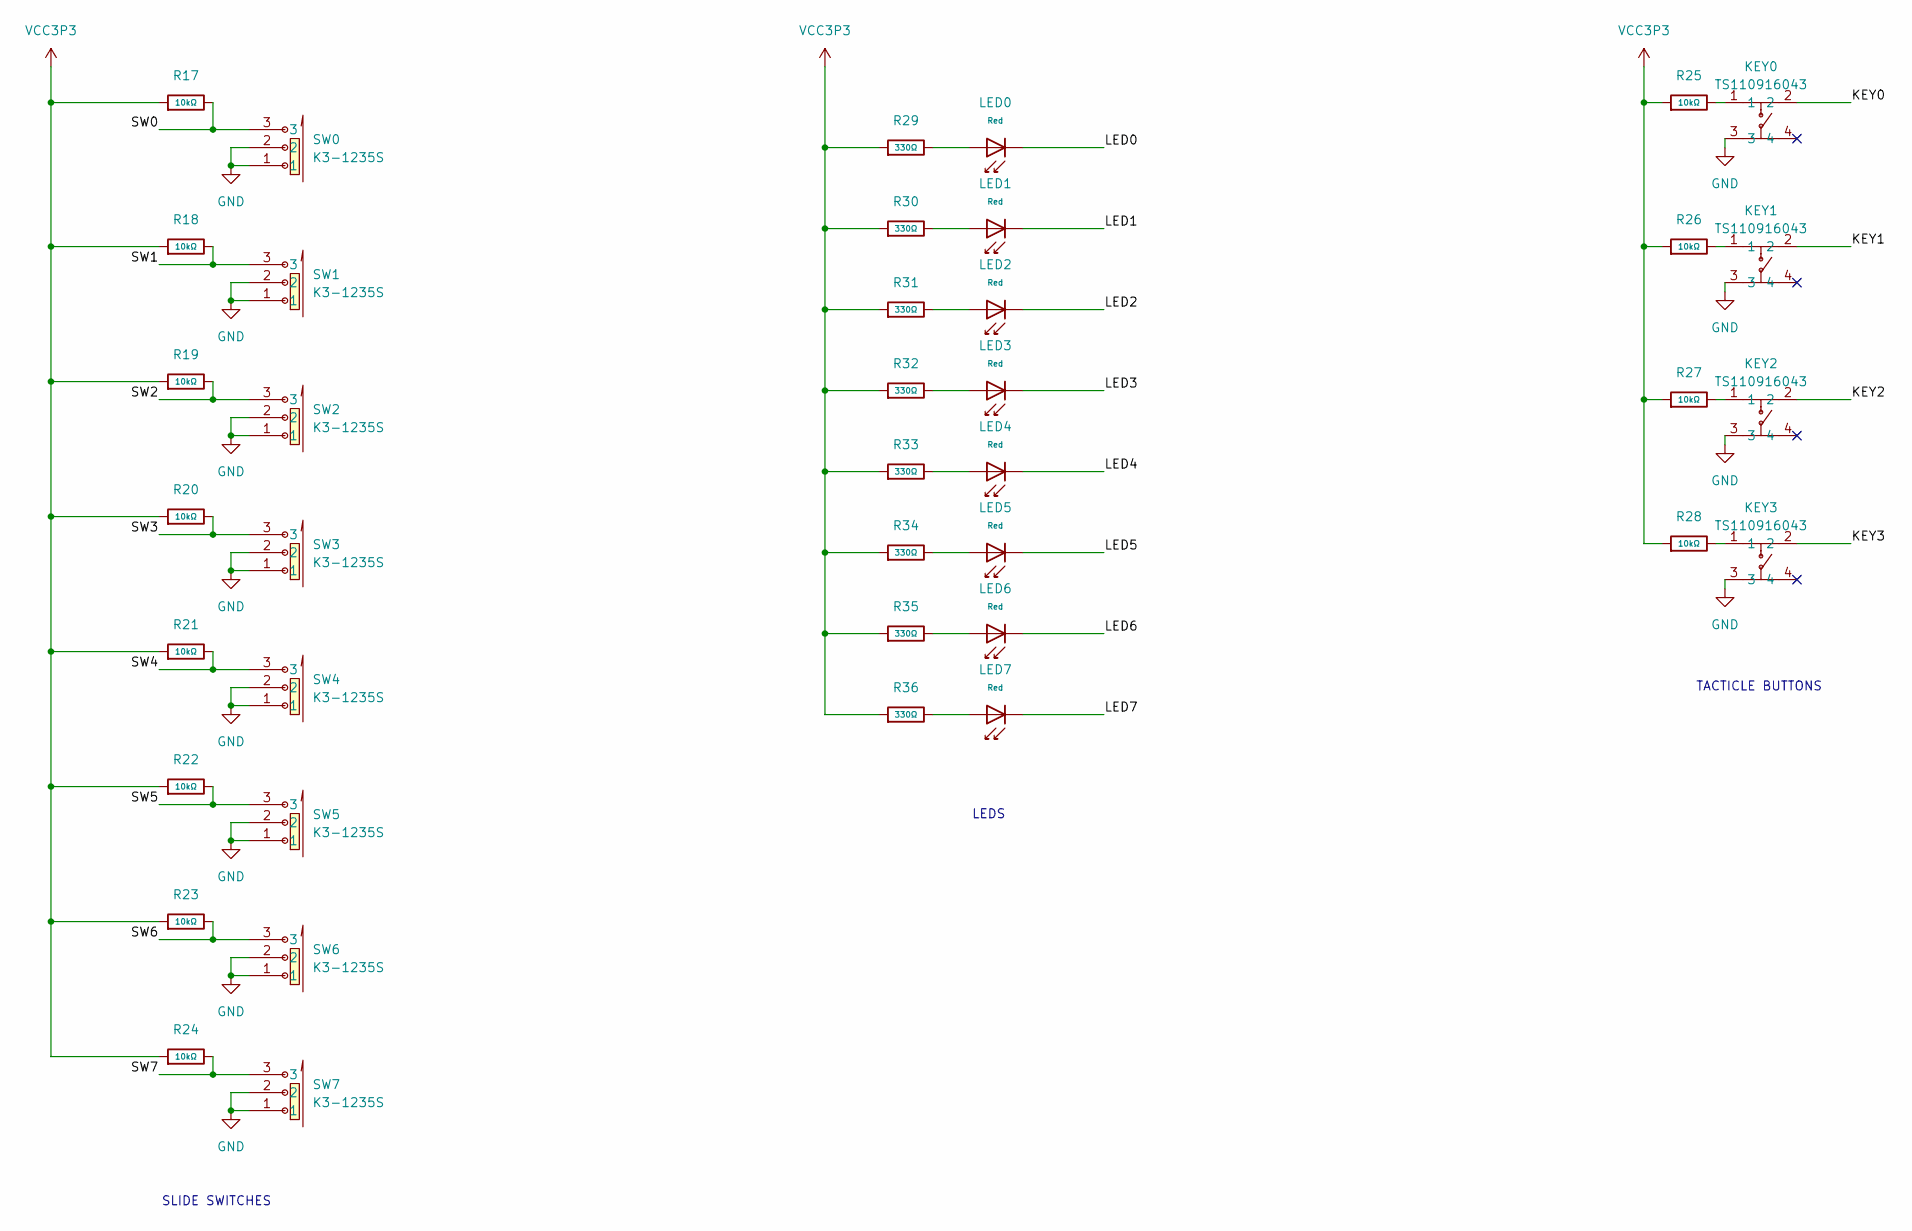
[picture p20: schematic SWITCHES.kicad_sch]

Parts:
KEY0, KEY1, KEY2, KEY3: TS110916043; SW-SMD_4P-L4.5-W4.5-P3.00-LS7.5; LCSC Part C22375348
LED0, LED1, LED2, LED3, LED4, LED5, LED6, LED7: Red; D_0603; Part KT-0603R; LCSC C2286
R17, R18, R19, R20, R21, R22, R23, R24, R25, R26, R27, R28: 10kΩ; R_0402; Overload Voltage (Max) 50V; Tolerance ±1%; Part 0402WGF1002TCE; LCSC C25744
R29, R30, R31, R32, R33, R34, R35, R36: 330Ω; R_0402; Overload Voltage (Max) 50V; Tolerance ±1%; Part 0402WGF3300TCE; LCSC C25104
SW0, SW1, SW2, SW3, SW4, SW5, SW6, SW7: K3-1235S; SW-SMD_K3-1235S-K1; LCSC Part C92660

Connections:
/SWITCHES/KEY0: KEY0.2
/SWITCHES/KEY1: KEY1.2
/SWITCHES/KEY2: KEY2.2
/SWITCHES/KEY3: KEY3.2
/SWITCHES/LED0: LED0.1
/SWITCHES/LED1: LED1.1
/SWITCHES/LED2: LED2.1
/SWITCHES/LED3: LED3.1
/SWITCHES/LED4: LED4.1
/SWITCHES/LED5: LED5.1
/SWITCHES/LED6: LED6.1
/SWITCHES/LED7: LED7.1
/SWITCHES/SW0: R17.2, SW0.3
/SWITCHES/SW1: R18.2, SW1.3
/SWITCHES/SW2: R19.2, SW2.3
/SWITCHES/SW3: R20.2, SW3.3
/SWITCHES/SW4: R21.2, SW4.3
/SWITCHES/SW5: R22.2, SW5.3
/SWITCHES/SW6: R23.2, SW6.3
/SWITCHES/SW7: R24.2, SW7.3
GND: KEY0.3, KEY1.3, KEY2.3, KEY3.3, SW0.1, SW0.2, SW1.1, SW1.2, SW2.1, SW2.2, SW3.1, SW3.2, SW4.1, SW4.2, SW5.1, SW5.2, SW6.1, SW6.2, SW7.1, SW7.2; also elsewhere on the board
unnamed: KEY0.1, R25.2
unnamed: KEY1.1, R26.2
unnamed: KEY2.1, R27.2
unnamed: KEY3.1, R28.2
unnamed: LED0.2, R29.2
unnamed: LED1.2, R30.2
unnamed: LED2.2, R31.2
unnamed: LED3.2, R32.2
unnamed: LED4.2, R33.2
unnamed: LED5.2, R34.2
unnamed: LED6.2, R35.2
unnamed: LED7.2, R36.2
VCC3P3: R17.1, R18.1, R19.1, R20.1, R21.1, R22.1, R23.1, R24.1, R25.1, R26.1, R27.1, R28.1, R29.1, R30.1, R31.1, R32.1, R33.1, R34.1, R35.1, R36.1; also elsewhere on the board

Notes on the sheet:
LEDS
TACTICLE BUTTONS
SLIDE SWITCHES

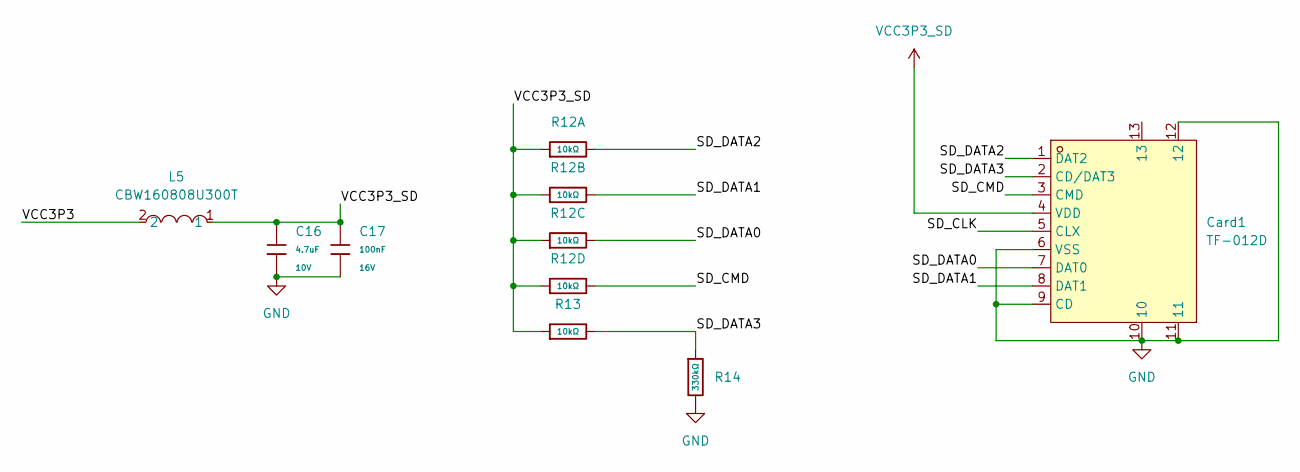
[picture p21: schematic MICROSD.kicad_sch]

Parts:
C16: 4.7uF; C_0402; Voltage Rated 10V; Tolerance ±20%; Part CL05A475MP5NRNC; LCSC C23733
C17: 100nF; C_0402; Voltage Rated 16V; Tolerance ±10%; Part CL05B104KO5NNNC; LCSC C1525
Card1: TF-012D; TF-SMD_TF-012; LCSC Part C2874207
L5: CBW160808U300T; L0603; LCSC Part C139178
R12: 10kΩ; R_0402x4; Tolerance ±5%; Part 4D02WGJ0103TCE; LCSC C25725
R13: 10kΩ; R_0402; Overload Voltage (Max) 50V; Tolerance ±1%; Part 0402WGF1002TCE; LCSC C25744
R14: 330kΩ; R_0402; Overload Voltage (Max) 50V; Tolerance ±1%; Part 0402WGF3303TCE; LCSC C25778

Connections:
/MICROSD/SD_CLK: Card1.5 (CLX)
/MICROSD/SD_CMD: Card1.3 (CMD), R12.5
/MICROSD/SD_DATA0: Card1.7 (DAT0), R12.6
/MICROSD/SD_DATA1: Card1.8 (DAT1), R12.7
/MICROSD/SD_DATA2: Card1.1 (DAT2), R12.8
/MICROSD/SD_DATA3: Card1.2 (CD/DAT3), R13.2, R14.1
/MICROSD/VCC3P3: L5.2
GND: C16.2, C17.2, Card1.6 (VSS), Card1.9 (CD), Card1.10, Card1.11, Card1.12, R14.2; also elsewhere on the board
VCC3P3_SD: C16.1, C17.1, Card1.4 (VDD), L5.1, R12.1, R12.2, R12.3, R12.4, R13.1

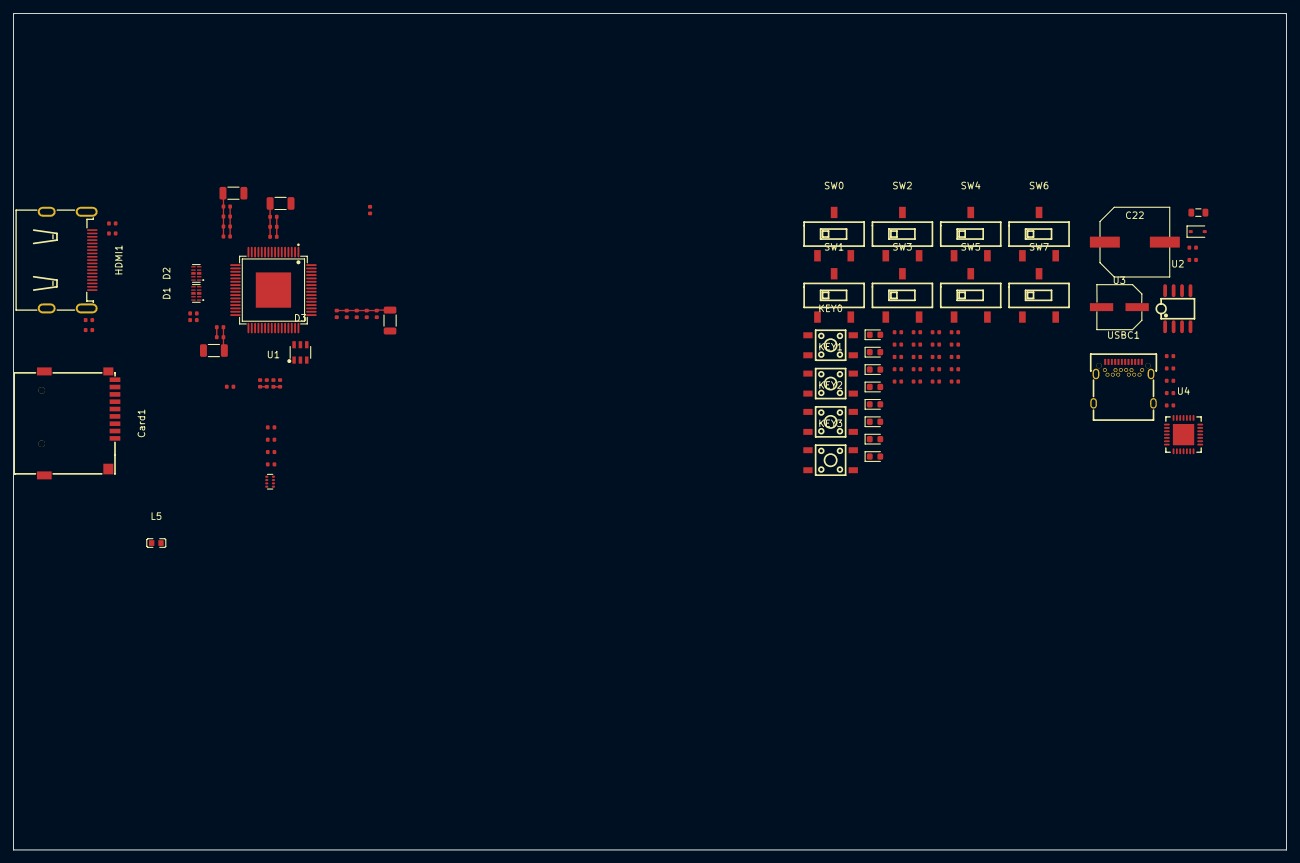
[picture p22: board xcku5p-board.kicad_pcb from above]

Board: 2 copper layers, 191.0 x 125.5 mm, 96 parts (0 on the bottom side), 67 nets.

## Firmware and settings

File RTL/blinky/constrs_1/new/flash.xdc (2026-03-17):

set_property PACKAGE_PIN T25 [get_ports clk_p]
set_property PACKAGE_PIN U25 [get_ports clk_n]
set_property IOSTANDARD LVDS [get_ports clk_p]
set_property IOSTANDARD LVDS [get_ports clk_n]
create_clock -period 10.000 -name sys_clk [get_ports clk_p]
create_generated_clock -name clk_200 -source [get_ports clk_p] -multiply_by 2 [get_pins mmcm_inst/CLKOUT0]

set_property PACKAGE_PIN A10 [get_ports led_a10]
set_property IOSTANDARD LVCMOS33 [get_ports led_a10]
set_property DRIVE 12 [get_ports led_a10]

set_property PACKAGE_PIN B10 [get_ports led_b10]
set_property IOSTANDARD LVCMOS33 [get_ports led_b10]
set_property DRIVE 12 [get_ports led_b10]

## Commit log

2026-03-12 Add pcb.md & Altium docs! - VGA circuit rev 1 done - VGA notes expanded
    [Breakout Board.PrjPcb, BreakoutBoard.PcbDoc, FPGA_IO.SchDoc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]
2026-03-17 Add RTL for working blinking LED Demo! - This demo blinks two of the onboard LEDs at two different speeds - Sources the input clock from the onboard crystal oscillator and generates a 200MHz clock us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
    [flash.xdc]
2026-03-17 Switch to real pins for VGA
2026-03-20 Continue developing PCB!
    [BOARD_GPIO.SchDoc, Breakout Board.PrjPcb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]
2026-03-20 Add Switches and Keys to the PCB. Add microsd card slot.
    [BOARD_GPIO.SchDoc, Breakout Board.PrjPcb, FPGA_GPIO.SchDoc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]
2026-03-21 Cleaning up pcb design for JLCPCB! Almost ready to fab.
    [BOARD_GPIO.SchDoc, Breakout Board.PrjPcb, FPGA_GPIO.SchDoc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]
2026-03-21 Finish revision one of PCB! Reconsidering paying for a custom PCB and instead going for the other ebay board...
    [BOARD_GPIO.SchDoc, Bill of Materials-BreakoutBoardBOM.xlsx, Breakout Board.PrjPcb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]
2026-03-25 Start working on HDMI circuit based on DE10
    [Breakout Board.PrjPcb, HDMI.SchDoc, PcbLib1.PcbLib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]
2026-03-26 Switching to KiCAD, and going for HDMI + Ethernet
    [BOARD_GPIO.SchDoc, Bill of Materials-BreakoutBoardBOM.xlsx, Breakout Board.PrjPcb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]
2026-03-26 Add SD card circuit
    [MICROSD.kicad_sch, xcku5p-board.kicad_pcb, xcku5p-board.kicad_sch]
2026-03-27 Add power circuit, switches, UART bridge
    [POWER.kicad_sch, SWITCHES.kicad_sch, UART_BRIDGE.kicad_sch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]
